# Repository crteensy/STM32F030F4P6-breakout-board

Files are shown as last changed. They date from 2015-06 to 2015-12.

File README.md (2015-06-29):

# STM32F030F4P6-breakout-board
STM32F030F4P6 breakout board pcb files and example code

Hackaday.io project: https://hackaday.io/project/4277-stm32f030f4p6-breakout-board  
(includes link to OSH Park for bare PCBs)

## Code::Blocks project
This repo includes a Code::Blocks project file which is pre-configured. However, it needs some adjustments to your own environment. These are the necessary steps:
* make sure then libopencm3 has been compiled as per their instructions
* correctly configure your compiler. The project looks for a compiler named "gcc-arm-none-eabi 4.9 2015q2". If you want to use a different one, change the project's top-level compiler to that.
* in the project's "Build Settings"->"Custom Variables": update the variable opencm3root to point at your libopencm3 root directory. Compiler and linker search paths use that variable.
* (optional) create a template: "File"->"Save Project as Template..."

The template (if you have created one; see the last step above) can then reused from within C::B's project wizard: "File"->"New"->"From Template" or "File"->"New"->"Project"->"User Templates"

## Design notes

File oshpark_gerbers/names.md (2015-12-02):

.GTL: top layer
.GBL: bottom layer
.GTS: top solder mask
.GBS: bottom solder mask
.GTO: top silk screen
.GBO: bottom silk screen
.GKO: board outline
.XLN: drills

.dri: drill info file

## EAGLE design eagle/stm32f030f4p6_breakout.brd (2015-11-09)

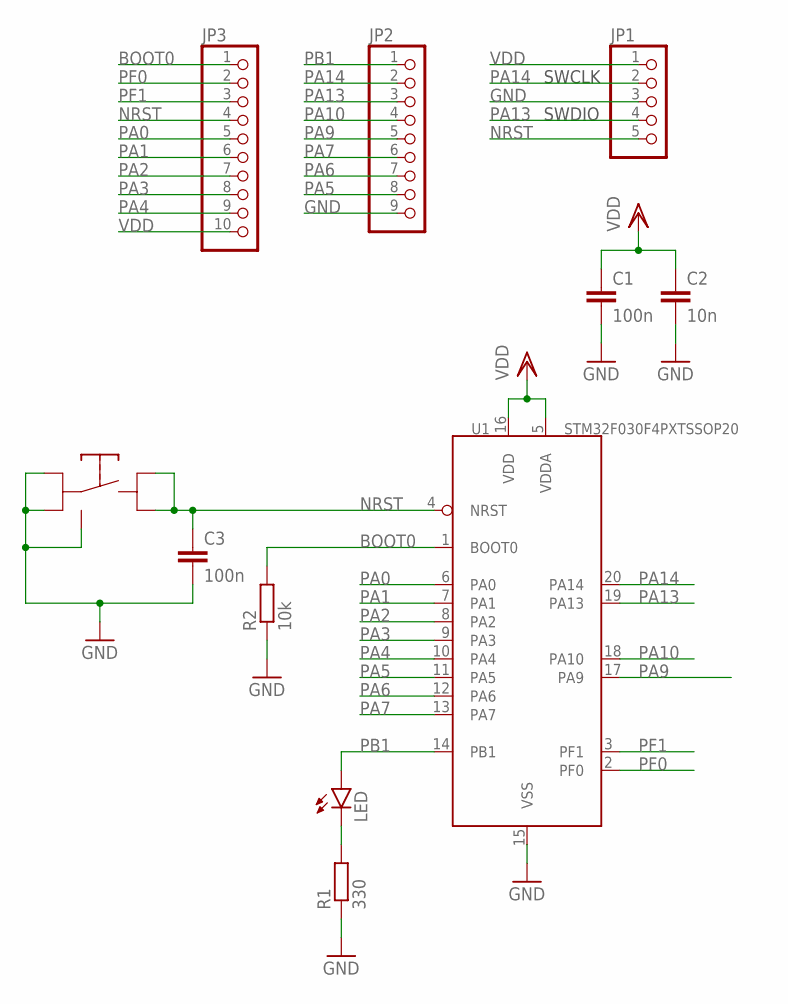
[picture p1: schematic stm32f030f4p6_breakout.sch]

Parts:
C1, C3: 100n; C0603
C2: 10n; C0603
JP1: PINHD-1X5/90; 1X05/90
JP2: PINHD-1X9; 1X09
JP3: PINHD-1X10; 1X10
LED: LED; LED-0603-CR
R1: 330; R0603
R2: 10k; R0603
RESET: KMR2XXG
U1: STM32F030F4PXTSSOP20; STM32F030F4PX_TSSOP20

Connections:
BOOT0: JP3.1, R2.2, U1.1 (BOOT0)
GND: C1.2, C2.2, C3.2, JP1.3, JP2.9, R1.1, R2.1, RESET.P$3 (3), RESET.P$4 (4), RESET.P$5 (G), U1.15 (VSS)
unnamed: LED.1 (C), R1.2
NRST: C3.1, JP1.5, JP3.4, RESET.P$1 (1), RESET.P$2 (2), U1.4 (NRST)
PA0: JP3.5, U1.6 (PA0)
PA1: JP3.6, U1.7 (PA1)
PA2: JP3.7, U1.8 (PA2)
PA3: JP3.8, U1.9 (PA3)
PA4: JP3.9, U1.10 (PA4)
PA5: JP2.8, U1.11 (PA5)
PA6: JP2.7, U1.12 (PA6)
PA7: JP2.6, U1.13 (PA7)
PA9: JP2.5, U1.17 (PA9)
PA10: JP2.4, U1.18 (PA10)
PA13: JP1.4, JP2.3, U1.19 (PA13)
PA14: JP1.2, JP2.2, U1.20 (PA14)
PB1: JP2.1, LED.2 (A), U1.14 (PB1)
PF0: JP3.2, U1.2 (PF0)
PF1: JP3.3, U1.3 (PF1)
VDD: C1.1, C2.1, JP1.1, JP3.10, U1.5 (VDDA), U1.16 (VDD)

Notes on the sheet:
SWDIO
SWCLK

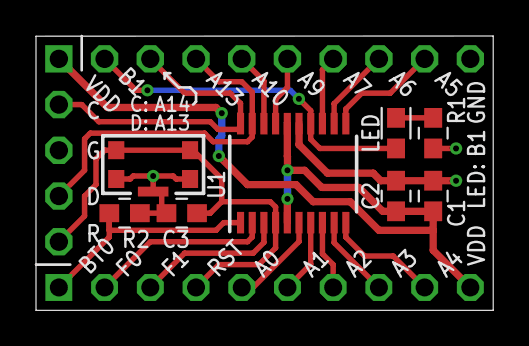
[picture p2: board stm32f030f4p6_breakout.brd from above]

Board: 2 copper layers, 25.4 x 15.2 mm, 11 parts (1 on the bottom side), 20 nets.

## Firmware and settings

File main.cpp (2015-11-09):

/* PB1 is connected to the onboard LED on the STM32F030F4P6 breakout board. */
#define PORT_LED_ONBOARD GPIOB
#define PIN_LED_ONBOARD GPIO1

#include <libopencm3/stm32/rcc.h>
#include <libopencm3/stm32/gpio.h>

#include <core/core.h>

/* set STM32 to clock by 48MHz from HSI oscillator */
static void clock_setup(void)
{
  rcc_clock_setup_in_hsi_out_48mhz();

  /* Enable clocks to the GPIO subsystems */
  rcc_periph_clock_enable(RCC_GPIOB);
}

static void gpio_setup(void)
{
  gpio_mode_setup(PORT_LED_ONBOARD, GPIO_MODE_OUTPUT, GPIO_PUPD_NONE, PIN_LED_ONBOARD);
}

int main(void)
{
  clock_setup();
  gpio_setup();

  /* setup systick to generate 2 LED flashes per second */
  systick_init();

  /* Do nothing in main loop */
  while (1)
  {
    static const uint16_t period = 500;
    static elapsedMillis timer = period;
    if (timer >= period)
    {
      timer = 0;
      gpio_toggle(PORT_LED_ONBOARD, PIN_LED_ONBOARD);
    }
  }
}

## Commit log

2015-07-13 added board files
    [breakout_noxtal_4.brd, breakout_noxtal_4.sch]
2015-11-09 - added BOOT0 pulldown - silkscreen type slightly increased to 35mil - wider supply tracks - minor changes to routing
    [stm32f030f4p6_breakout.brd, stm32f030f4p6_breakout.sch]
2015-12-02 added gerbers
    [stm32f030f4p6_breakout_5.GBL, stm32f030f4p6_breakout_5.GBO, stm32f030f4p6_breakout_5.GBS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]
